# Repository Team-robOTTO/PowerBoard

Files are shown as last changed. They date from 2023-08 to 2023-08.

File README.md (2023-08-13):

# PowerBoard
Bosch 18V Battery-based Power supply for KUKA YouBots

## Folder Overview

- mechanic: Everything related to mounting of batteries and boards -> FreeCAD
- pcb     : all schematics for the PCBs -> KICAD
- software: Software for the teensy 3.2 on the main PCB

## Parts list

Not yet complete!

### Main Power board
- 3x p channel mosfets: 942-IRF5210PBF; https://www.mouser.de/ProductDetail/Infineon-Technologies/IRF5210PBF?qs=9%252BKlkBgLFf3S3YiL4ijtLg%3D%3D (3x2,87€)
- 4x hall sensor: 630-ACHS-7124-000E; https://www.mouser.de/ProductDetail/Broadcom-Avago/ACHS-7124-000E?qs=gZXFycFWdAOkIb94nIF9uA%3D%3D (4x4,73€)
- 3x protection diode: 771-BAT54S-T/R; https://www.mouser.de/ProductDetail/Nexperia/BAT54S215?qs=me8TqzrmIYVOaf3j7zH0Wg%3D%3D (3x0,20€)
- 1x 5V regulator: 511-L7805CV; https://www.mouser.de/ProductDetail/STMicroelectronics/L7805CV?qs=9NrABl3fj%2FqplZAHiYUxWg%3D%3D (1x0,69€)
- 7x XT60: 426-FIT0587; https://www.mouser.de/ProductDetail/DFRobot/FIT0587?qs=w%2Fv1CP2dgqpRvlGrUpUtJQ%3D%3D (7x1,50€)
- 6x 4k7: 603-RC0805JR-134K7L; https://www.mouser.de/ProductDetail/YAGEO/RC0805JR-134K7L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 (6x0,10€)
- 4x 680R: 603-RC0805JR-10680RL; https://www.mouser.de/ProductDetail/YAGEO/RC0805JR-10680RL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 (6x0,11€)
- 4x 1uF: 710-885012107015; https://www.mouser.de/ProductDetail/Wurth-Elektronik/885012107015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 (4x0,10€)
- 4x 1nF: 80-C0805C102K3RAUTO; https://www.mouser.de/ProductDetail/KEMET/C0805C102K3RACAUTO?qs=MyNHzdoqoQKWoDSELmF8XQ%3D%3D (4x0,09€)
- 3x diode: 637-P2500J; https://www.mouser.de/ProductDetail/Diotec-Semiconductor/P2500J?qs=OlC7AqGiEDnhOnRO%252BjStSw%3D%3D (3x2,45€)
- 4x 2 pole terminal block plug: 490-TBP01P1-508-02BE; https://www.mouser.de/ProductDetail/CUI-Devices/TBP01P1-508-02BE?qs=PzGy0jfpSMuRa64vjc7Npw%3D%3D (4x0,86€)
- 4x 2 pole terminal block PCB socket: 490-TBP01R2-508-02BE; https://www.mouser.de/ProductDetail/CUI-Devices/TBP01R2-508-02BE?qs=PzGy0jfpSMtI214KtO%2FmIg%3D%3D (4x0,51€)
- 1x 7 pole terminal block socket: 490-TBP01R2-508-07BE; https://www.mouser.de/ProductDetail/CUI-Devices/TBP01R2-508-07BE?qs=PzGy0jfpSMv8M4EGbXc3CQ%3D%3D (1x1,00€)
- 1x 7 pole terminal block plug: 490-TBP01P1-508-07BE; https://www.mouser.de/ProductDetail/CUI-Devices/TBP01P1-508-07BE?qs=PzGy0jfpSMv0m1paAwlB0Q%3D%3D (1x1,94€)

- price: 45€ / PCB

### 24V Board Emergency Off
- 2x p channel mosfets: 942-IRF5210PBF; https://www.mouser.de/ProductDetail/Infineon-Technologies/IRF5210PBF?qs=9%252BKlkBgLFf3S3YiL4ijtLg%3D%3D (2x2,87€)
- 3x XT60: 426-FIT0587; https://www.mouser.de/ProductDetail/DFRobot/FIT0587?qs=w%2Fv1CP2dgqpRvlGrUpUtJQ%3D%3D (3x1,50€)
- 3x 4k7: 603-RC0805JR-134K7L; https://www.mouser.de/ProductDetail/YAGEO/RC0805JR-134K7L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 (3x0,10€)
- 1x terminal block plug: 490-TBP01P1-508-02BE; https://www.mouser.de/ProductDetail/CUI-Devices/TBP01P1-508-02BE?qs=PzGy0jfpSMuRa64vjc7Npw%3D%3D (1x0,86€)
- 1x terminal block PCB socket: 490-TBP01R2-508-02BE; https://www.mouser.de/ProductDetail/CUI-Devices/TBP01R2-508-02BE?qs=PzGy0jfpSMtI214KtO%2FmIg%3D%3D (1x0,51€)

- price: 7,41€ / PCB

## 15V Power Supply for NUC

- see exported BOM
- 1x 3 pole terminal socket: https://www.mouser.de/ProductDetail/CUI-Devices/TBP01R2-508-03BE?qs=PzGy0jfpSMvsLipzvwxOIA%3D%3D (1x0,60€)
- 1x 3 pole terminal plug: https://www.mouser.de/ProductDetail/CUI-Devices/TBP01P1-508-03BE?qs=PzGy0jfpSMsyMkSLNya%2Fkw%3D%3D (1x1,06€)

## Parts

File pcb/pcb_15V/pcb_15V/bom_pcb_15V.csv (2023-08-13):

Source: | /Users/ingabrockhage/Documents/robotto/powerboard/pcb_15V/pcb_15V/pcb_15V.kicad_sch
Date: | 2022 November 28, Monday 17:50:35
Tool: | Eeschema (6.0.9-0)
Generator: | /Applications/KiCad/KiCad.app/Contents/SharedSupport/plugins/bom_csv_grouped_by_value.py
Component Count: | 22
Individual Components:
Item | Qty |  | Reference(s) | Value | LibPart | Footprint | Datasheet
 |  |  | CBTS1 | 270n | Device:C | Capacitor_SMD:C_1206_3216Metric_Pad1.33x1.80mm_HandSolder | ~
 |  |  | CCF1 | 12p | Device:C | Capacitor_SMD:C_0603_1608Metric_Pad1.08x0.95mm_HandSolder | ~
 |  |  | CF1 | 15n | Device:C | Capacitor_SMD:C_0603_1608Metric_Pad1.08x0.95mm_HandSolder | ~
 |  |  | CIN1 | 470u | Device:C_Polarized | Capacitor_SMD:CP_Elec_16x17.5 | ~
 |  |  | CIN2 | 22u | Device:C_Polarized | Capacitor_SMD:C_2220_5650Metric_Pad1.97x5.40mm_HandSolder | ~
 |  |  | CIN3 | 1u | Device:C | Capacitor_SMD:C_1206_3216Metric_Pad1.33x1.80mm_HandSolder | ~
 |  |  | CIVCC1 | 1u | Device:C | Capacitor_SMD:C_1206_3216Metric_Pad1.33x1.80mm_HandSolder | ~
 |  |  | CL1 | 120p | Device:C | Capacitor_SMD:C_0603_1608Metric_Pad1.08x0.95mm_HandSolder | ~
 |  |  | COUT1 | 100u | Device:C_Polarized | Capacitor_SMD:CP_Elec_8x11.9 | ~
 |  |  | COUT2 | 100u | Device:C_Polarized | Capacitor_SMD:CP_Elec_8x11.9 | ~
 |  |  | J1 | Conn_01x02_Female | Connector:Conn_01x02_Female | Connector_AMASS:AMASS_XT60-F_1x02_P7.20mm_Vertical | ~
 |  |  | J2 | Conn_01x02_Female | Connector:Conn_01x02_Female | Connector_PinHeader_1.27mm:PinHeader_1x02_P1.27mm_Vertical | ~
 |  |  | J3 | Conn_01x02_Female | Connector:Conn_01x02_Female | Connector_AMASS:AMASS_XT60-F_1x02_P7.20mm_Vertical | ~
 |  |  | L1 | 5.6uH | Device:L | Inductor_SMD:L_12x12mm_H8mm | ~
 |  |  | Q_HIGH1 | Q_NMOS_GDS | Device:Q_NMOS_GDS | Package_TO_SOT_SMD:TO-252-3_TabPin2 | ~
 |  |  | Q_LOW1 | Q_NMOS_GDS | Device:Q_NMOS_GDS | Package_TO_SOT_SMD:TO-252-3_TabPin2 | ~
 |  |  | R1 | 100k | Device:R | Resistor_SMD:R_0603_1608Metric_Pad0.98x0.95mm_HandSolder | ~
 |  |  | R2 | 8k | Device:R | Resistor_SMD:R_0603_1608Metric_Pad0.98x0.95mm_HandSolder | ~
 |  |  | RF1 | 6.65k | Device:R | Resistor_SMD:R_0603_1608Metric_Pad0.98x0.95mm_HandSolder | ~
 |  |  | RFREQ1 | 20k | Device:R | Resistor_SMD:R_0603_1608Metric_Pad0.98x0.95mm_HandSolder | ~
 |  |  | Rsense1 | 1.1k | Device:R | Resistor_SMD:R_0603_1608Metric_Pad0.98x0.95mm_HandSolder | ~
 |  |  | U1 | TLF51801ELV | TLF51801ELV:TLF51801ELV | pcb_15V:SOP65P600X170-15N-V2
Collated Components:
Item | Qty | Mouser Link | Reference(s) | Value | LibPart | Footprint | Datasheet
1 | 1 | https://www.mouser.de/ProductDetail/KEMET/C1206C273K5RAC7800?qs=LcahVQl%252BFeQn6lQFhtybCg%3D%3D | CBTS1 | 270n | Device:C | Capacitor_SMD:C_1206_3216Metric_Pad1.33x1.80mm_HandSolder | ~
2 | 1 | https://www.mouser.de/ProductDetail/KEMET/C0603C120J5GAC7867?qs=xVzHhAug4FAmFbi2HEHwrg%3D%3D | CCF1 | 12p | Device:C | Capacitor_SMD:C_0603_1608Metric_Pad1.08x0.95mm_HandSolder | ~
3 | 1 | https://www.mouser.de/ProductDetail/KEMET/C0603C153K5RACTU?qs=lJgFhCQulnr6ANOSHxstzw%3D%3D | CF1 | 15n | Device:C | Capacitor_SMD:C_0603_1608Metric_Pad1.08x0.95mm_HandSolder | ~
4 | 1 | https://www.mouser.de/ProductDetail/Panasonic/EEE-FK1H471AM?qs=tqvsmoK%252ByvFak1dN7eEiAA%3D%3D | CIN1 | 470u | Device:C_Polarized | Capacitor_SMD:CP_Elec_16x17.5 | ~
5 | 1 | https://www.mouser.de/ProductDetail/KEMET/C2220C226M5R2CAUTO?qs=%2FP4PrV2zI7PFm%2FXGh1rWvw%3D%3D | CIN2 | 22u | Device:C_Polarized | Capacitor_SMD:C_2220_5650Metric_Pad1.97x5.40mm_HandSolder | ~
6 | 1 | https://www.mouser.de/ProductDetail/KEMET/C1206C105K5RAC7800?qs=HwP6sGvP66YvUShJICNDDg%3D%3D | CIN3 | 1u | Device:C | Capacitor_SMD:C_1206_3216Metric_Pad1.33x1.80mm_HandSolder | ~
 | 1 | https://www.mouser.de/ProductDetail/KEMET/C1206C105K4RACTU?qs=mhB89zxvawkhvFSUXW8mIw%3D%3D | CIVCC1 | 1u | Device:C | Capacitor_SMD:C_1206_3216Metric_Pad1.33x1.80mm_HandSolder | ~
7 | 1 | https://www.mouser.de/ProductDetail/KEMET/C0603C121J5GAC7867?qs=xVzHhAug4FCquoT6gvwGLA%3D%3D | CL1 | 120p | Device:C | Capacitor_SMD:C_0603_1608Metric_Pad1.08x0.95mm_HandSolder | ~
8 | 2 | https://www.mouser.de/ProductDetail/Rubycon/6SW100M?qs=BJlw7L4Cy78HK%252BOoCsAFqw%3D%3D | COUT1, COUT2 | 100u | Device:C_Polarized | Capacitor_SMD:CP_Elec_8x11.9 | ~
9 | 2 | https://www.mouser.de/ProductDetail/SparkFun/PRT-10474?qs=WyAARYrbSnYJaRDMiD9g2w%3D%3D | J1, J3 | Conn_01x02_Female | Connector:Conn_01x02_Female | Connector_AMASS:AMASS_XT60-F_1x02_P7.20mm_Vertical | ~
10 | 1 | https://www.mouser.de/ProductDetail/Harwin/M50-3030242?qs=%252BdQmOuGyFcEgq9CAdD7HGw%3D%3D | J2 | Conn_01x02_Female | Connector:Conn_01x02_Female | Connector_PinHeader_1.27mm:PinHeader_1x02_P1.27mm_Vertical | ~
11 | 1 | https://www.mouser.de/ProductDetail/Coilcraft/MSS1278T-562MLD?qs=zCSbvcPd3paIkbhzcsbw8g%3D%3D | L1 | 5.6uH | Device:L | Inductor_SMD:L_12x12mm_H8mm | ~
12 | 2 | https://www.mouser.de/ProductDetail/Infineon-Technologies/IPD50N06S4L12ATMA2?qs=OwbwYO03UsLkML6Aev1Vcw%3D%3D | Q_HIGH1, Q_LOW1 | Q_NMOS_GDS | Device:Q_NMOS_GDS | Package_TO_SOT_SMD:TO-252-3_TabPin2 | ~
13 | 1 | https://www.mouser.de/ProductDetail/Panasonic/ERJ-3EKF1003V?qs=H7k1u0Mp9JSqh2R2gj46DA%3D%3D | R1 | 100k | Device:R | Resistor_SMD:R_0603_1608Metric_Pad0.98x0.95mm_HandSolder | ~
14 | 1 | https://www.mouser.de/ProductDetail/YAGEO/RT0603BRE078KL?qs=ABvmyp11Kkg9dWVeDLdutQ%3D%3D | R2 | 8k | Device:R | Resistor_SMD:R_0603_1608Metric_Pad0.98x0.95mm_HandSolder | ~
15 | 1 | https://www.mouser.de/ProductDetail/Panasonic/ERJ-3EKF6651V?qs=66DK8nO8gJCLxReoLjqhXA%3D%3D | RF1 | 6.65k | Device:R | Resistor_SMD:R_0603_1608Metric_Pad0.98x0.95mm_HandSolder | ~
16 | 1 | https://www.mouser.de/ProductDetail/Panasonic/ERJ-3EKF2002V?qs=66DK8nO8gJB3y0uxig0mNg%3D%3D | RFREQ1 | 20k | Device:R | Resistor_SMD:R_0603_1608Metric_Pad0.98x0.95mm_HandSolder | ~
17 | 1 | https://www.mouser.de/ProductDetail/Panasonic/ERJ-3EKF1101V?qs=zp1CF8hTeCiNy6F%252B%252B5%252BYzw%3D%3D | Rsense1 | 1.1k | Device:R | Resistor_SMD:R_0603_1608Metric_Pad0.98x0.95mm_HandSolder | ~
18 | 1 | https://www.mouser.de/ProductDetail/Infineon-Technologies/TLF51801ELV?qs=y2kkmE52mdOdhUJngasMaw%3D%3D | U1 | TLF51801ELV | TLF51801ELV:TLF51801ELV | pcb_15V:SOP65P600X170-15N-V2

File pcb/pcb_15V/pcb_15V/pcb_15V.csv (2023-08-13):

Source: | /Users/ingabrockhage/Documents/robotto/powerboard/pcb_15V/pcb_15V/pcb_15V.kicad_sch
Date: | 2022 November 28, Monday 17:50:35
Tool: | Eeschema (6.0.9-0)
Generator: | /Applications/KiCad/KiCad.app/Contents/SharedSupport/plugins/bom_csv_grouped_by_value.py
Component Count: | 22
Individual Components:
Item | Qty | Reference(s) | Value | LibPart | Footprint | Datasheet
 |  | CBTS1 | 270n | Device:C | Capacitor_SMD:C_1206_3216Metric_Pad1.33x1.80mm_HandSolder | ~
 |  | CCF1 | 12p | Device:C | Capacitor_SMD:C_0603_1608Metric_Pad1.08x0.95mm_HandSolder | ~
 |  | CF1 | 15n | Device:C | Capacitor_SMD:C_0603_1608Metric_Pad1.08x0.95mm_HandSolder | ~
 |  | CIN1 | 470u | Device:C_Polarized | Capacitor_SMD:CP_Elec_16x17.5 | ~
 |  | CIN2 | 22u | Device:C_Polarized | Capacitor_SMD:C_2220_5650Metric_Pad1.97x5.40mm_HandSolder | ~
 |  | CIN3 | 1u | Device:C | Capacitor_SMD:C_1206_3216Metric_Pad1.33x1.80mm_HandSolder | ~
 |  | CIVCC1 | 1u | Device:C | Capacitor_SMD:C_1206_3216Metric_Pad1.33x1.80mm_HandSolder | ~
 |  | CL1 | 120p | Device:C | Capacitor_SMD:C_0603_1608Metric_Pad1.08x0.95mm_HandSolder | ~
 |  | COUT1 | 100u | Device:C_Polarized | Capacitor_SMD:CP_Elec_8x11.9 | ~
 |  | COUT2 | 100u | Device:C_Polarized | Capacitor_SMD:CP_Elec_8x11.9 | ~
 |  | J1 | Conn_01x02_Female | Connector:Conn_01x02_Female | Connector_AMASS:AMASS_XT60-F_1x02_P7.20mm_Vertical | ~
 |  | J2 | Conn_01x02_Female | Connector:Conn_01x02_Female | Connector_PinHeader_1.27mm:PinHeader_1x02_P1.27mm_Vertical | ~
 |  | J3 | Conn_01x02_Female | Connector:Conn_01x02_Female | Connector_AMASS:AMASS_XT60-F_1x02_P7.20mm_Vertical | ~
 |  | L1 | 5.6uH | Device:L | Inductor_SMD:L_12x12mm_H8mm | ~
 |  | Q_HIGH1 | Q_NMOS_GDS | Device:Q_NMOS_GDS | Package_TO_SOT_SMD:TO-252-3_TabPin2 | ~
 |  | Q_LOW1 | Q_NMOS_GDS | Device:Q_NMOS_GDS | Package_TO_SOT_SMD:TO-252-3_TabPin2 | ~
 |  | R1 | 100k | Device:R | Resistor_SMD:R_0603_1608Metric_Pad0.98x0.95mm_HandSolder | ~
 |  | R2 | 8k | Device:R | Resistor_SMD:R_0603_1608Metric_Pad0.98x0.95mm_HandSolder | ~
 |  | RF1 | 6.65k | Device:R | Resistor_SMD:R_0603_1608Metric_Pad0.98x0.95mm_HandSolder | ~
 |  | RFREQ1 | 20k | Device:R | Resistor_SMD:R_0603_1608Metric_Pad0.98x0.95mm_HandSolder | ~
 |  | Rsense1 | 1.1k | Device:R | Resistor_SMD:R_0603_1608Metric_Pad0.98x0.95mm_HandSolder | ~
 |  | U1 | TLF51801ELV | TLF51801ELV:TLF51801ELV | pcb_15V:SOP65P600X170-15N-V2
Collated Components:
Item | Qty | Reference(s) | Value | LibPart | Footprint | Datasheet
1 | 1 | CBTS1 | 270n | Device:C | Capacitor_SMD:C_1206_3216Metric_Pad1.33x1.80mm_HandSolder | ~
2 | 1 | CCF1 | 12p | Device:C | Capacitor_SMD:C_0603_1608Metric_Pad1.08x0.95mm_HandSolder | ~
3 | 1 | CF1 | 15n | Device:C | Capacitor_SMD:C_0603_1608Metric_Pad1.08x0.95mm_HandSolder | ~
4 | 1 | CIN1 | 470u | Device:C_Polarized | Capacitor_SMD:CP_Elec_16x17.5 | ~
5 | 1 | CIN2 | 22u | Device:C_Polarized | Capacitor_SMD:C_2220_5650Metric_Pad1.97x5.40mm_HandSolder | ~
6 | 2 | CIN3, CIVCC1 | 1u | Device:C | Capacitor_SMD:C_1206_3216Metric_Pad1.33x1.80mm_HandSolder | ~
7 | 1 | CL1 | 120p | Device:C | Capacitor_SMD:C_0603_1608Metric_Pad1.08x0.95mm_HandSolder | ~
8 | 2 | COUT1, COUT2 | 100u | Device:C_Polarized | Capacitor_SMD:CP_Elec_8x11.9 | ~
9 | 2 | J1, J3 | Conn_01x02_Female | Connector:Conn_01x02_Female | Connector_AMASS:AMASS_XT60-F_1x02_P7.20mm_Vertical | ~
10 | 1 | J2 | Conn_01x02_Female | Connector:Conn_01x02_Female | Connector_PinHeader_1.27mm:PinHeader_1x02_P1.27mm_Vertical | ~
11 | 1 | L1 | 5.6uH | Device:L | Inductor_SMD:L_12x12mm_H8mm | ~
12 | 2 | Q_HIGH1, Q_LOW1 | Q_NMOS_GDS | Device:Q_NMOS_GDS | Package_TO_SOT_SMD:TO-252-3_TabPin2 | ~
13 | 1 | R1 | 100k | Device:R | Resistor_SMD:R_0603_1608Metric_Pad0.98x0.95mm_HandSolder | ~
14 | 1 | R2 | 8k | Device:R | Resistor_SMD:R_0603_1608Metric_Pad0.98x0.95mm_HandSolder | ~
15 | 1 | RF1 | 6.65k | Device:R | Resistor_SMD:R_0603_1608Metric_Pad0.98x0.95mm_HandSolder | ~
16 | 1 | RFREQ1 | 20k | Device:R | Resistor_SMD:R_0603_1608Metric_Pad0.98x0.95mm_HandSolder | ~
17 | 1 | Rsense1 | 1.1k | Device:R | Resistor_SMD:R_0603_1608Metric_Pad0.98x0.95mm_HandSolder | ~
18 | 1 | U1 | TLF51801ELV | TLF51801ELV:TLF51801ELV | pcb_15V:SOP65P600X170-15N-V2

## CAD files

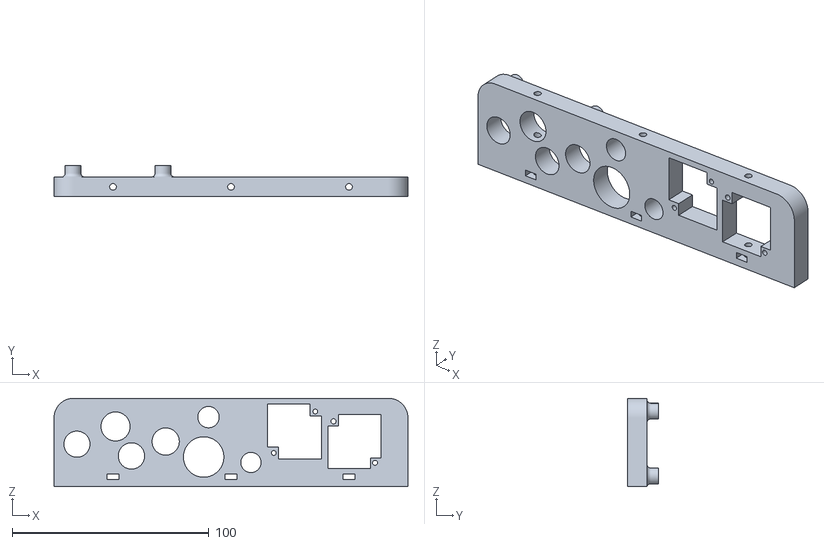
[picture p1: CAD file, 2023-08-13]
mechanic/base-plate/the_wall.stl
180.0 x 16.0 x 45.0

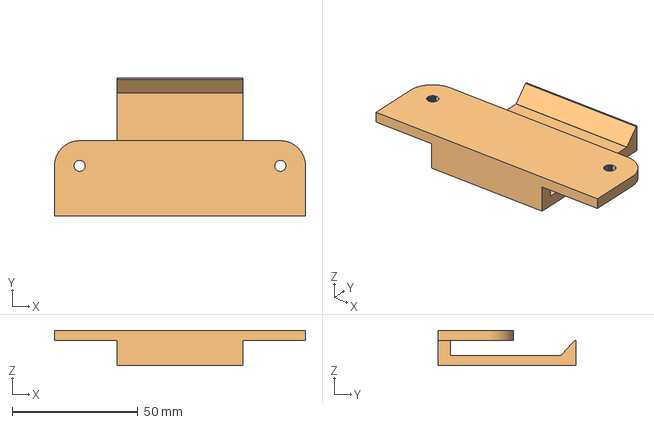
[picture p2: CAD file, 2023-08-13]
mechanic/battery-holder/battery-holder.FCStd
100.0 x 55.0 x 14.0 mm
Body003 (Meshed)

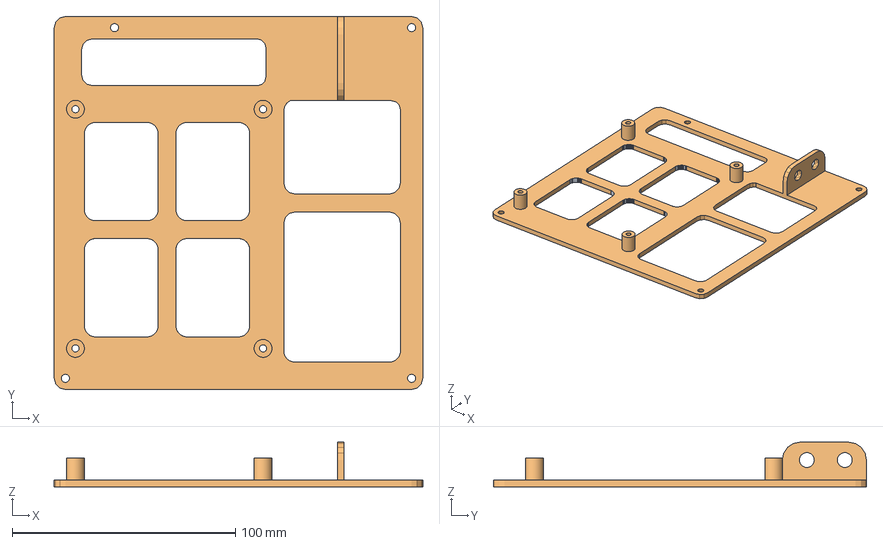
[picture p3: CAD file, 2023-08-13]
mechanic/mount/powerboard_mount.FCStd
165.0 x 167.0 x 20.0 mm
Fillet (Meshed)

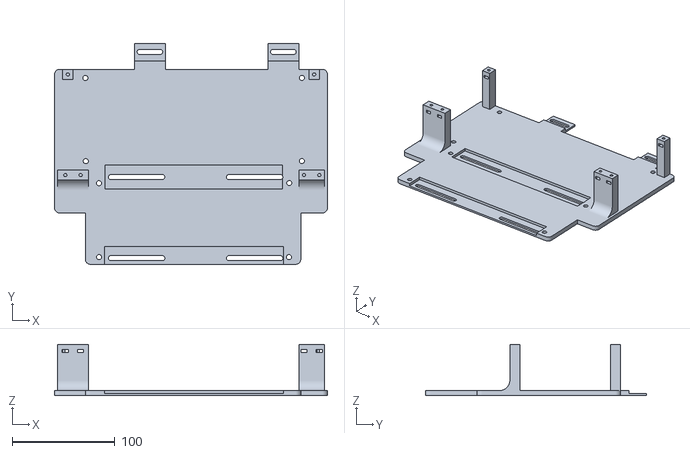
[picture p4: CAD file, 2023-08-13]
mechanic/base-plate/base_plate.stl
266.0 x 215.0 x 50.0

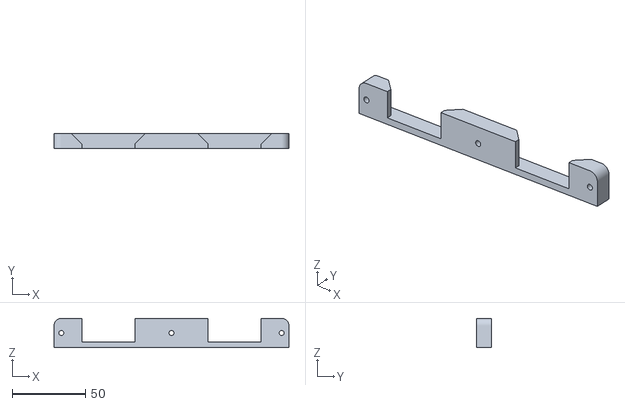
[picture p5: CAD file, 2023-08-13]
mechanic/battery-holder/battery-holder-bracket.stl
160.0 x 10.0 x 20.0

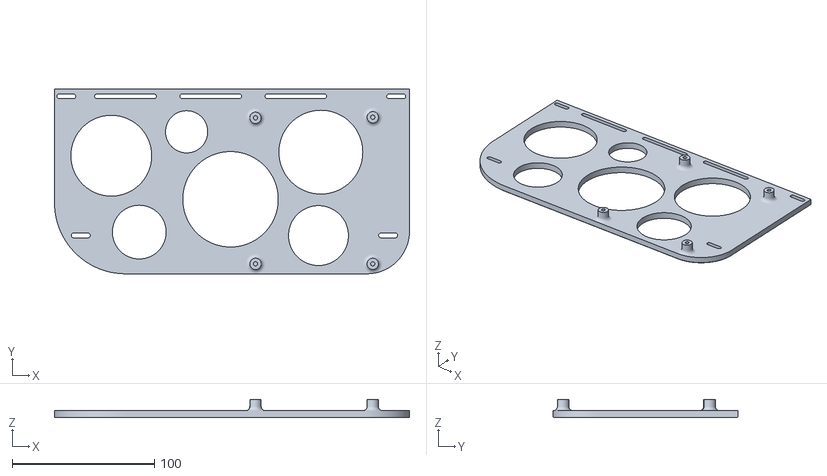
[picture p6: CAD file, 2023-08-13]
mechanic/base-plate/top_plate.stl
250.0 x 130.0 x 13.0

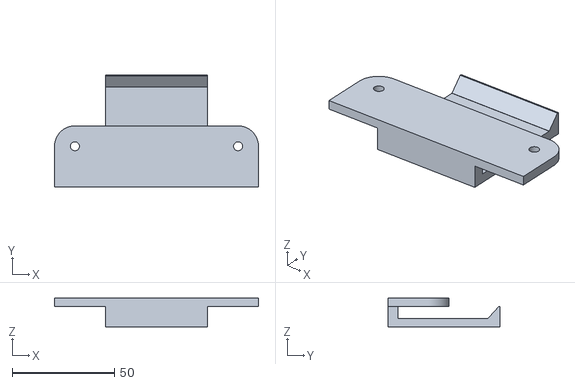
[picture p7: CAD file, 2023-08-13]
mechanic/battery-holder/battery-transport.stl
100.0 x 55.0 x 14.0

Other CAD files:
mechanic/mount/powerboard_mount.stl

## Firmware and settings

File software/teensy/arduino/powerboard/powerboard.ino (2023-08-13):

/*
 * robOTTOs powerboard teensy firmware
 * main file (powerboard.ino)
 * created: 16/MAY/2021 
 */

#include "power_control.h"

PowerControl pc;

unsigned long time;

//bool toggle;

void setup()
{
  Serial.begin(9600);

  time = millis();

 // toggle = true;
}

void loop()
{
  pc.run();

  if( (time + 1000 ) < millis() ) // every 1000ms
  {
    time = millis();
    Serial.print(pc.getChannelValue(PowerControl::PS));
    Serial.print("\t");
    Serial.print(pc.getChannelValue(PowerControl::BAT1));
    Serial.print("\t");
    Serial.print(pc.getChannelValue(PowerControl::BAT2));
    Serial.print("\t");
    Serial.print(pc.getChannelValue(PowerControl::I1));
    Serial.print("\t");
    Serial.println(pc.getChannelValue(PowerControl::I2));

    //toggle = !toggle;
    //pc.controlHighSideSwitch(PowerControl::BASE, toggle);
  }
}

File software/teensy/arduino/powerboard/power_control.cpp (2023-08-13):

/*
 * robOTTOs powerboard teensy firmware
 * power control class (power_control.cpp)
 * created: 16/MAY/2021 
 */

#include "power_control.h"

PowerControl::PowerControl()
: m_bat1(BAT_EMPTY, PIN_LED_BAT1_RED, PIN_LED_BAT1_GREEN) 
, m_bat2(BAT_EMPTY, PIN_LED_BAT2_RED, PIN_LED_BAT2_GREEN)
, m_ext(PS_PLUGGED_IN, PIN_LED_EXT_RED, PIN_LED_EXT_GREEN)
, m_adc()
{
    // init ADC
    m_adc.begin();

    pinMode(PIN_HIGH_SIDE_BASE, OUTPUT);
    digitalWrite(PIN_HIGH_SIDE_BASE, HIGH);
    pinMode(PIN_HIGH_SIDE_ARM, OUTPUT);
    digitalWrite(PIN_HIGH_SIDE_ARM, HIGH);
}

void PowerControl::run()
{
    updateAdcChannels();

    m_bat1.run(m_valueBat1);
    m_bat2.run(m_valueBat2);
    m_ext.run(m_valuePs);
}

uint16_t PowerControl::readAdc(uint8_t channel)
{
    return m_adc.readADC(channel);
}

uint16_t PowerControl::readAdcVoltage(enum PowerControl::adc_ch ch)
{
    //return readAdc(ch);
    float calc = (float)readAdc(ch) * (5000.0f / 1024.0f) / 1900.0f * (1900.0f + 10000.0f); // TODO: calc voltage
    // 1275
    // 10000
    // u = uges * 1275 / (1275 + 10000) 
    return (uint16_t)calc;
}

void PowerControl::updateAdcChannels()
{
    m_valuePs = readAdcVoltage(PowerControl::PS);
    m_valueBat1 = readAdcVoltage(PowerControl::BAT1);
    m_valueBat2 = readAdcVoltage(PowerControl::BAT2);
    m_valueI1 = readAdc(PowerControl::I1);
    m_valueI2 = readAdc(PowerControl::I2);

}

uint16_t PowerControl::getChannelValue(enum PowerControl::adc_ch ch)
{
    switch(ch)
    {
        case PowerControl::PS:  return m_valuePs;
                                break;
        case PowerControl::BAT1:return m_valueBat1;
                                break;
        case PowerControl::BAT2:return m_valueBat2;
                                break;
        case PowerControl::I1:  return m_valueI1;
                                break;
        case PowerControl::I2:  return m_valueI2;
                                break;
        default:                return 0;
    };
    return 0;
}

void PowerControl::controlHighSideSwitch(enum PowerControl::high_side_switch_ch ch, bool st)
{
    if(ch == PowerControl::BASE)
    {
        digitalWrite(PIN_HIGH_SIDE_BASE, st);
    }
    else if(ch == PowerControl::ARM)
    {
        digitalWrite(PIN_HIGH_SIDE_ARM, st);
    }
}
